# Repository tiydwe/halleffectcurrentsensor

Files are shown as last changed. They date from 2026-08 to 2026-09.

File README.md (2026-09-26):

# Handheld Hall Effect Current Sensor

This is a handheld hall effect current sensor, a device used to measure current without needing to directly touch the circuit being measured.
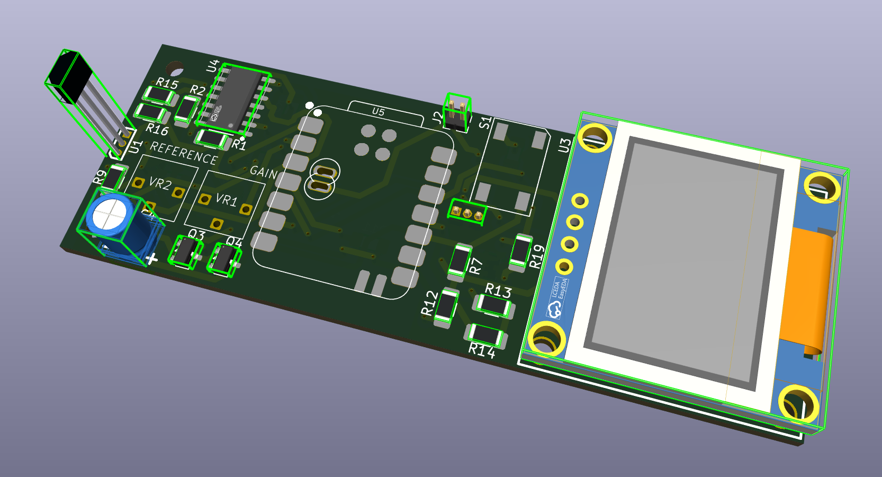
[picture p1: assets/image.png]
screenshot of a pcb

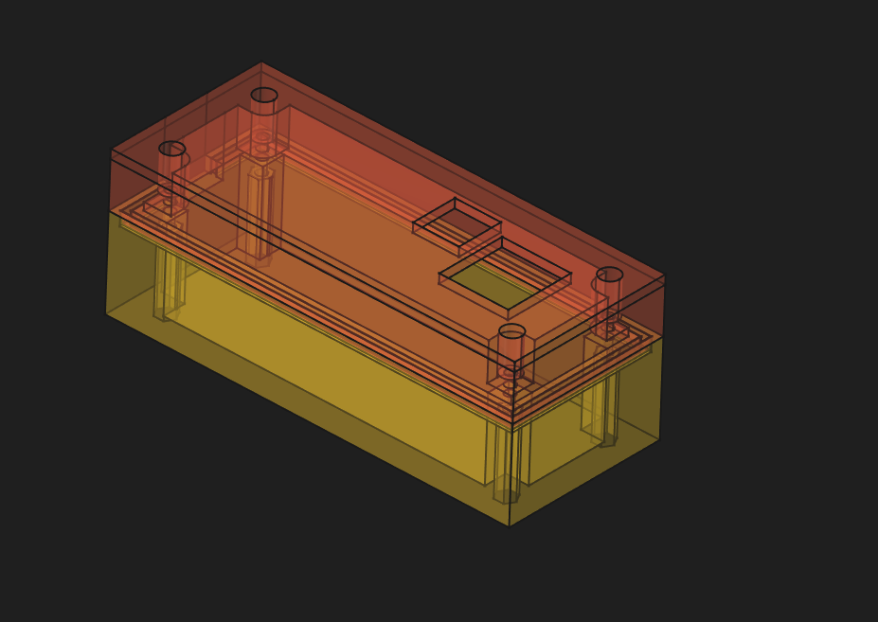
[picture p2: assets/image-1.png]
screenshot of cad model


# Features
* Completely contained on one handheld case, including battery
* Self powered!
* OLED screen for easy measurement
* Two adjustable calibration resistors for easy calibration

# Assembly
The handheld hall effect current sensor is easily assembled with just 4 parts:
* The bottom part of case
* The battery, which sits in the bottom part of case
* The PCB, which goes between the top and bottom part of the case
* The top part of the case

It is held together with 4 M2 screws and 4 M2 nuts.

# Technical stuff

The hall effect voltage output is fed into an insturmentation amplifier to subtract it from the known zero current voltage and amplify the result. Both the gain and the reference voltage can be easily adjusted with two variable resistors on the PCB. The output of the insturmentation amplifier goes into a Seeed Studio nrf52840 microcontroller's ADC where it is processed. The current reading is then written onto the OLED.

The whole system is powered from a lipo battery, which is regulated to 3.3v by the Seeed Studio microcontroller. An additional [3.3v to 5v off-board converter](https://www.amazon.com/Comidox-Module-Voltage-Converter-0-9-5V/dp/B07L76KLRY/) is used to power the op amp and hall effect sensor.

# IMAGES
Full schematic:
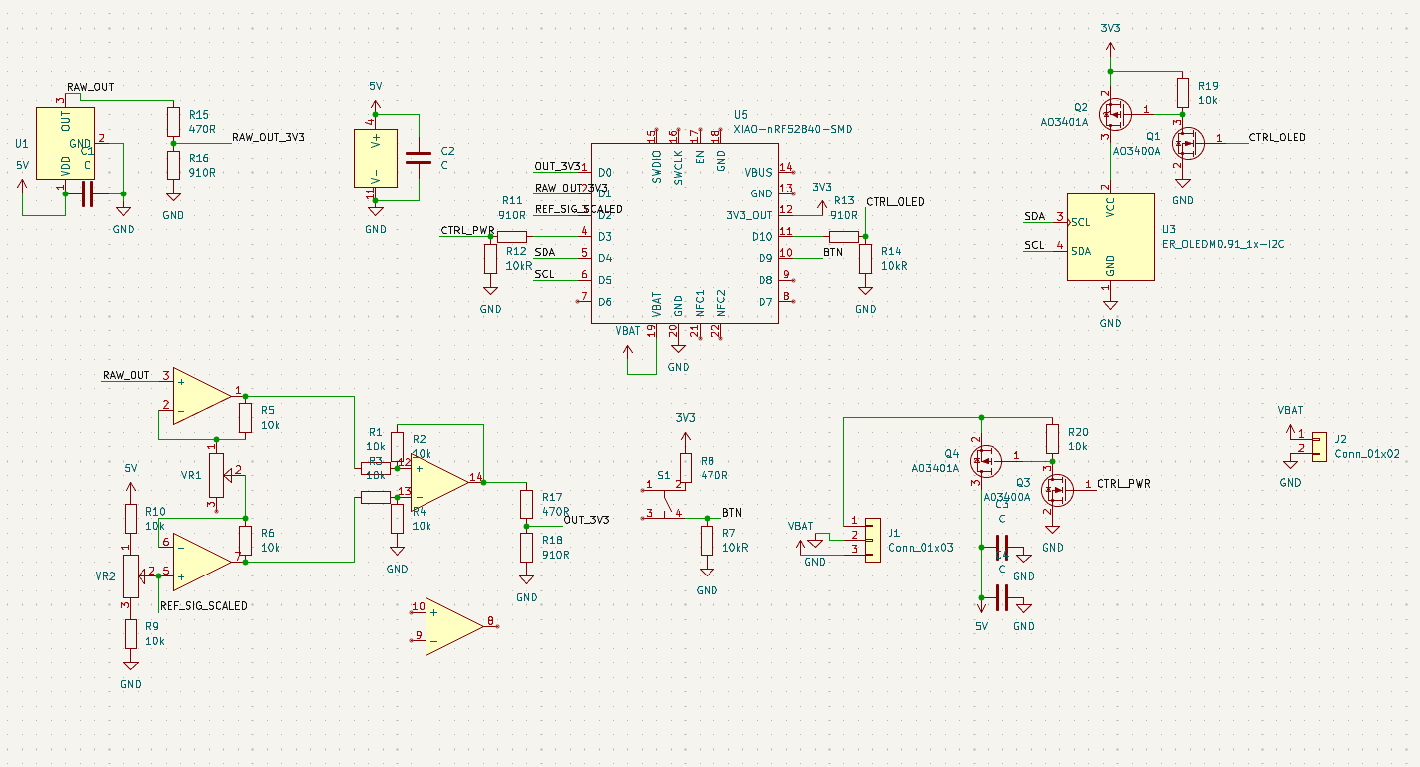
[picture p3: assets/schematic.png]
screenshot of schematic


PCB layout:
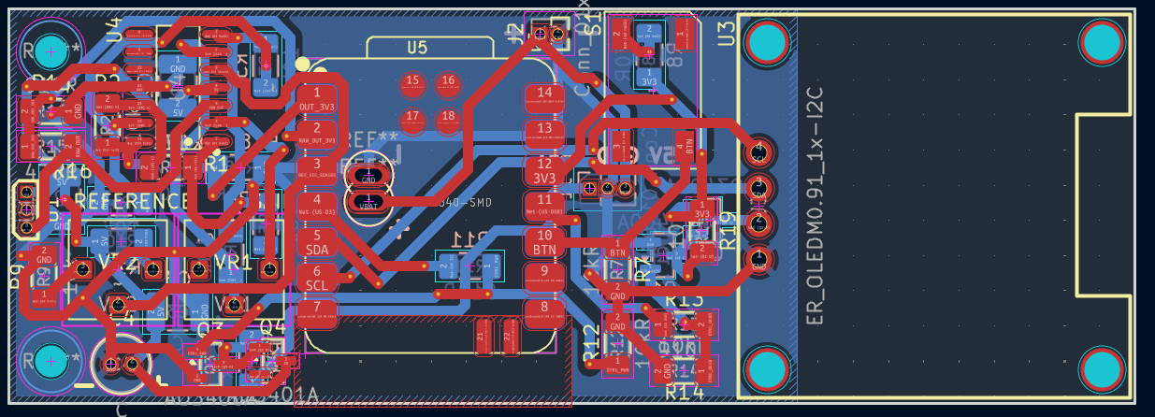
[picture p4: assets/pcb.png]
screenshot of pcb layout


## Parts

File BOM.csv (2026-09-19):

Item Name | Qty | Price (total) (USD) | Item link | Notes
C18189021 | 5 | $0.97 | https://www.lcsc.com/product-detail/C18189021.html | Hall effect sensor
C7463387 | 3 | $1.46 | https://www.lcsc.com/product-detail/C7463387.html | Op amp + 2 extras in case I break one
C5248080 | 1 | 2.3 | https://www.lcsc.com/product-detail/C5248080.html? | OLED
C49451350 | 10 | 0.42 | https://www.lcsc.com/product-detail/C49451350.html | 100nF caps
C53261042 | 20 | 0.45 | https://www.lcsc.com/product-detail/C53261042.html | N-mosfet
C2836398 | 20 | 0.52 | https://www.lcsc.com/product-detail/C2836398.html | P-mosfet
C7528752 | 10 | 0.26 | https://www.lcsc.com/product-detail/C7528752.html | Tactile button
C2933707 | 100 | 0.63 | https://www.lcsc.com/product-detail/C2933707.html | 470 ohm resistor
C2930433 | 100 | 0.59 | https://www.lcsc.com/product-detail/C2930433.html | 910 ohm resistor
LCSC shipping (est) |  | 15 |  | approx
XIAO nRF52840 | 1 | 9.99 | https://www.seeedstudio.com/Seeed-XIAO-BLE-nRF52840-p-5201.html
Seeed studio shipping |  | 7.26
1Ah lipo battery | 1 | 6.49 | https://www.amazon.com/AKZYTUE-1000mAh-Battery-Rechargeable-Protection/dp/B0FRFYJ32K
Ferrite core (pack of 5) | 1 | 8.09 | https://www.amazon.com/gp/product/B07YJXRN6V/ref=ewc_pr_img_2
M2 screw kit | 1 | 8.3 | https://www.amazon.com/Fgruh-1200PCS-Assortment-Washers-Assorted/dp/B0FGV5K8BT?th=1 | Best way I could find to get screws
PCB - OSHPARK | 1 | 17.35 |  | Cheaper than JLCPCB when including shipping
Total Price (USD): |  | $80.08

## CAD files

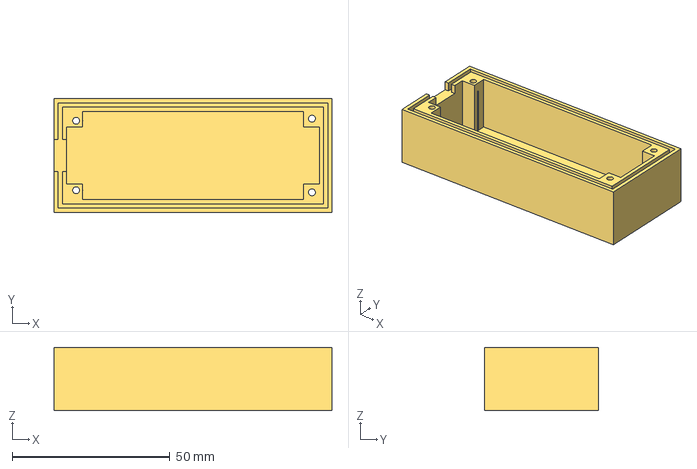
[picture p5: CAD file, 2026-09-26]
cad/case-bottom.step
88.0 x 36.0 x 20.0 mm

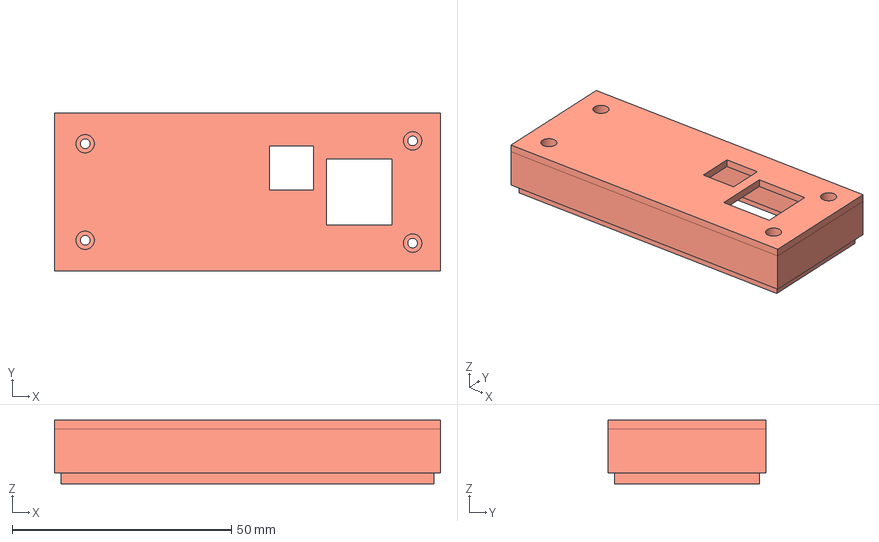
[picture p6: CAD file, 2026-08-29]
production/case-top.step
88.0 x 36.0 x 14.5 mm

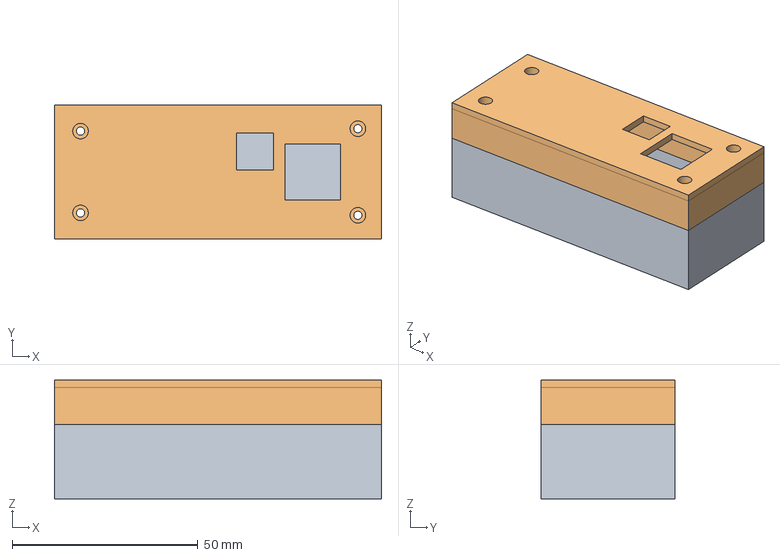
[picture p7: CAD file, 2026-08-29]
cad/case.FCStd
88.0 x 36.0 x 32.0 mm
bottom
top

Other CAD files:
cad/case-top.step
production/case-bottom.step

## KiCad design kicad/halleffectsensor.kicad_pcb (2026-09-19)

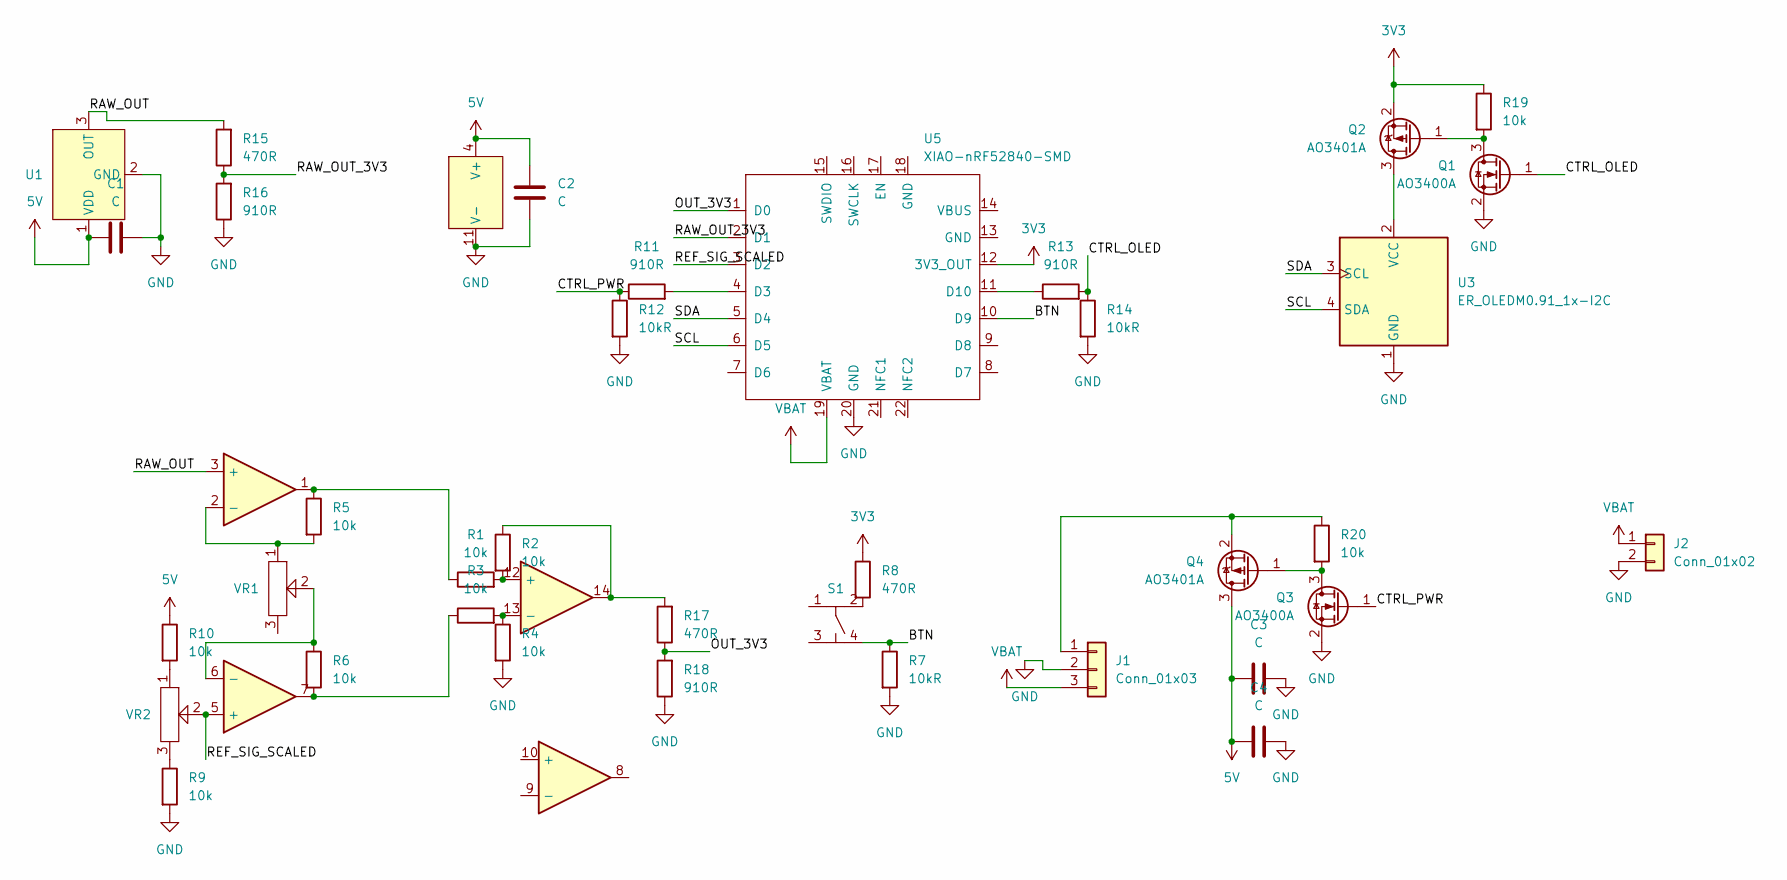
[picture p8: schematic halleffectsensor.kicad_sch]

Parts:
C1, C2, C3: C; C_1210_3225Metric_Pad1.33x2.70mm_HandSolder
C4: C; C_Radial_D4.0mm_H7.0mm_P1.50mm
J1: Conn_01x03; PinHeader_1x03_P1.27mm_Vertical
J2: Conn_01x02; PinHeader_1x02_P1.27mm_Vertical
Q1, Q3: AO3400A; SOT-23
Q2, Q4: AO3401A; SOT-23
R1, R2, R3, R4, R5, R6, R9, R10, R19, R20: 10k; R_1206_3216Metric_Pad1.30x1.75mm_HandSolder
R7, R12, R14: 10kR; R_1206_3216Metric_Pad1.30x1.75mm_HandSolder
R8, R15, R17: 470R; R_1206_3216Metric_Pad1.30x1.75mm_HandSolder
R11, R13, R16, R18: 910R; R_1206_3216Metric_Pad1.30x1.75mm_HandSolder
S1: SOIC-4
U1: TO-92S-3_L4.1-W1.7-P1.27-L
U3: ER_OLEDM0.91_1x-I2C; OLED-TH_L27.8-W27.2-P2.54_C9900033791
U4: SOP-14_L8.6-W3.9-P1.27-LS6.0-BL
U5: XIAO-nRF52840-SMD
VR1, VR2: Potentiometer_3_pi

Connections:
3V3: Q2.2 (S), R8.1, R19.1, U5.12 (3V3_OUT)
5V: C1.1, C2.2, C3.2, C4.2, Q4.3 (D), R10.1, U1.1 (VDD), U4.4 (V+)
/BTN: R7.1, S1.4, U5.10 (D9)
/CTRL_OLED: Q1.1 (G), R13.2, R14.1
/CTRL_PWR: Q3.1 (G), R11.1, R12.1
/OUT_3V3: R17.1, R18.2, U5.1 (D0)
/RAW_OUT: R15.2, U1.3 (OUT), U4.3 (+)
/RAW_OUT_3V3: R15.1, R16.2, U5.2 (D1)
/REF_SIG_SCALED: U4.5 (+), U5.3 (D2), VR2.2
/SCL: U3.4 (SDA), U5.6 (D5)
/SDA: U3.3 (SCL), U5.5 (D4)
GND: C1.2, C2.1, C3.1, C4.1, J1.2, J2.2, Q1.2 (S), Q3.2 (S), R4.2, R7.2, R9.2, R12.2, R14.2, R16.1, R18.1, U1.2 (GND), U3.1 (GND), U4.11 (V-), U5.20 (GND)
unnamed: J1.1, Q4.2 (S), R20.1
unnamed: Q1.3 (D), Q2.1 (G), R19.2
unnamed: Q2.3 (D), U3.2 (VCC)
unnamed: Q3.3 (D), Q4.1 (G), R20.2
unnamed: R1.1, R5.1, U4.1
unnamed: R3.1, R6.2, U4.7
unnamed: R8.2, S1.2
unnamed: R9.1, VR2.3
unnamed: R10.2, VR2.1
unnamed: R2.1, R17.2, U4.14
unnamed: R5.2, U4.2 (-), VR1.1
unnamed: R6.1, U4.6 (-), VR1.2
unnamed: R1.2, R2.2, U4.12 (+)
unnamed: R3.2, R4.1, U4.13 (-)
unnamed: R11.2, U5.4 (D3)
unnamed: R13.1, U5.11 (D10)
VBAT: J1.3, J2.1, U5.19 (VBAT)

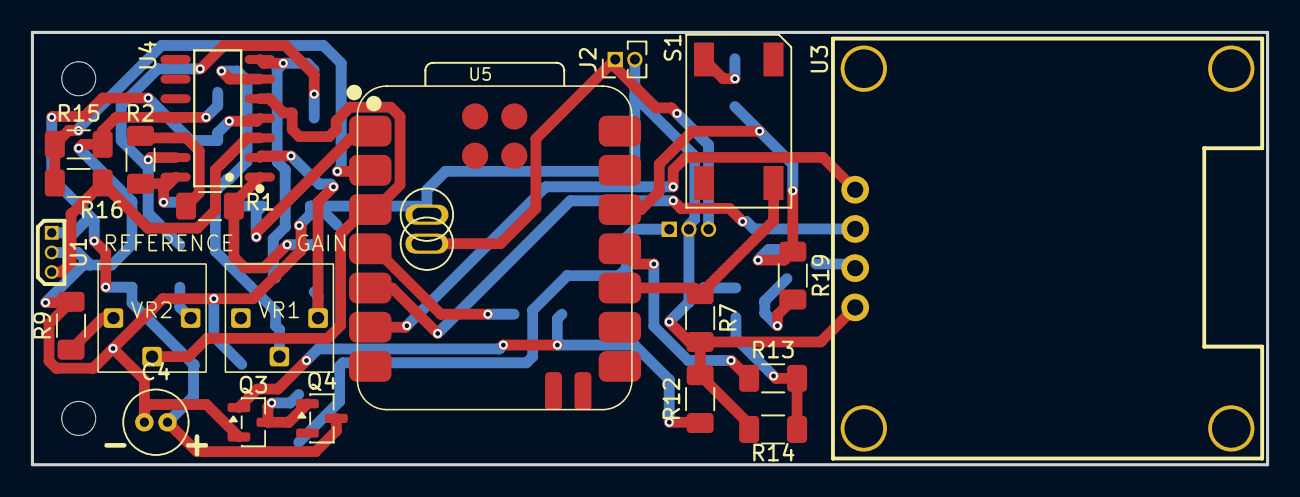
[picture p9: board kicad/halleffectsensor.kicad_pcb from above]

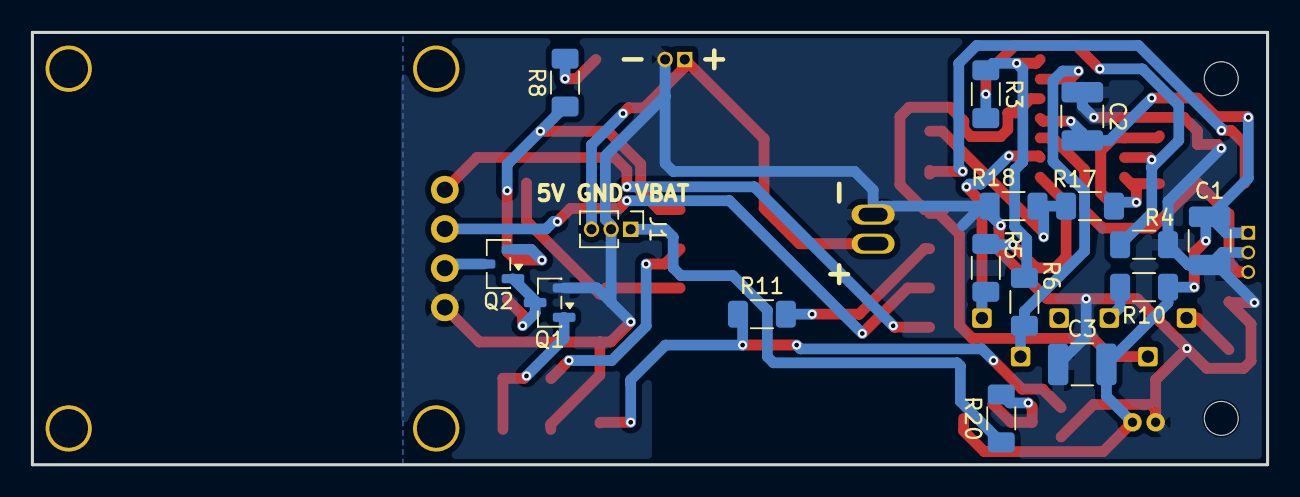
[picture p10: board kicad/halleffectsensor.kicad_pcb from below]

Board: 2 copper layers, 80.0 x 28.0 mm, 37 parts (16 on the bottom side), 29 nets.

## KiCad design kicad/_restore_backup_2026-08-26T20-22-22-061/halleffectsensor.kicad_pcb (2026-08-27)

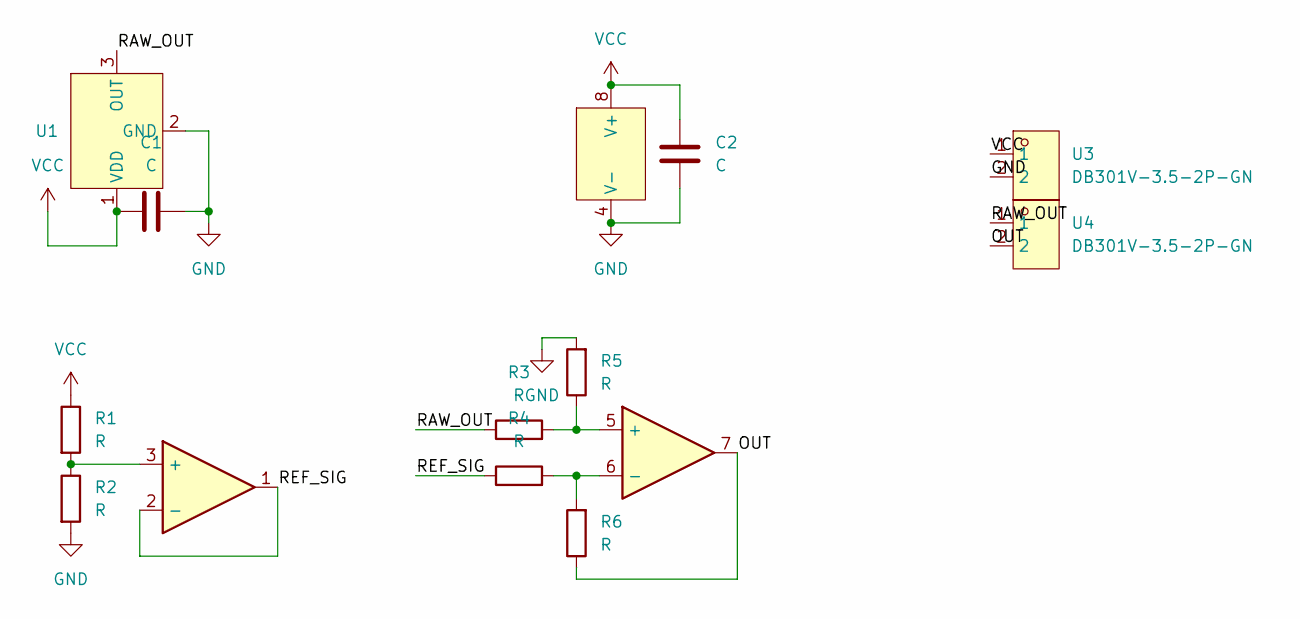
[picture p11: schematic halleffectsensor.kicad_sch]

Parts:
C1, C2: C; C_1210_3225Metric_Pad1.33x2.70mm_HandSolder
R1, R2, R3, R4, R5, R6: R; R_Axial_DIN0204_L3.6mm_D1.6mm_P7.62mm_Horizontal
U1: TO-92S-3_L4.1-W1.7-P1.27-L
U2: COS5532DT; DIP-8_L9.3-W6.4-P2.54-LS7.6-BL; LCSC Part C5155885
U3, U4: DB301V-3.5-2P-GN; CONN-TH_DB301V-3.5-2P-GN; LCSC Part C695629

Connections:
/OUT: R6.1, U2.7, U4.2
/RAW_OUT: R3.1, U1.3 (OUT), U4.1
/REF_SIG: R4.1, U2.1, U2.2 (-)
GND: C1.2, C2.1, R2.2, R5.2, U1.2 (GND), U2.4 (V-), U3.2
unnamed: R1.2, R2.1, U2.3 (+)
unnamed: R3.2, R5.1, U2.5 (+)
unnamed: R4.2, R6.2, U2.6 (-)
VCC: C1.1, C2.2, R1.1, U1.1 (VDD), U2.8 (V+), U3.1

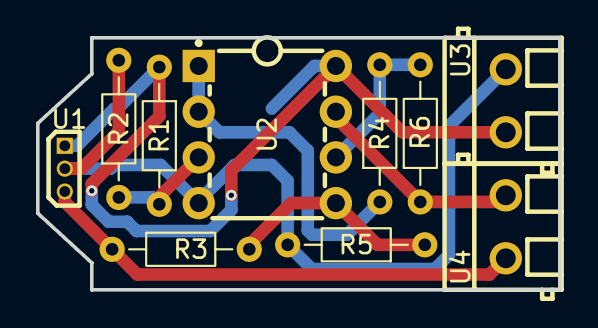
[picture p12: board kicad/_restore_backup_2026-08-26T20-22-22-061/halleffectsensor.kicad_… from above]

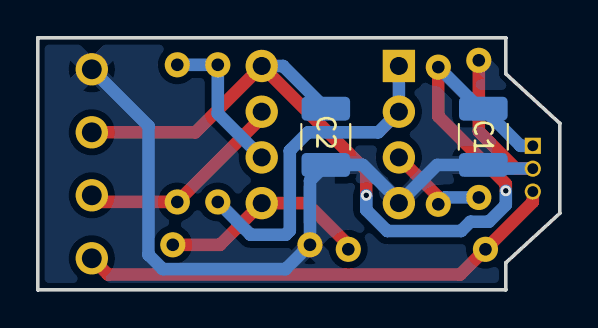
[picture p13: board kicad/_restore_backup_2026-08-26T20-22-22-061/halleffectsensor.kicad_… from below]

Board: 2 copper layers, 29.0 x 14.0 mm, 12 parts (2 on the bottom side), 8 nets.

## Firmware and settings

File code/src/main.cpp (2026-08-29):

#include <Arduino.h>
#include <bluefruit.h>
#include <Adafruit_SPIFlash.h>

#include "config.h"
#include "OLED.h"
#include "sense.h"
#include "utility.h"

#if defined(CUSTOM_CS) && defined(CUSTOM_SPI)
  Adafruit_FlashTransport_SPI flashTransport(CUSTOM_CS, CUSTOM_SPI);

#elif defined(ARDUINO_ARCH_ESP32)
  Adafruit_FlashTransport_ESP32 flashTransport;

#else
  #if defined(EXTERNAL_FLASH_USE_QSPI)
    Adafruit_FlashTransport_QSPI flashTransport;

  #elif defined(EXTERNAL_FLASH_USE_SPI)
    Adafruit_FlashTransport_SPI flashTransport(EXTERNAL_FLASH_USE_CS, EXTERNAL_FLASH_USE_SPI);

  #else
    #error No QSPI/SPI flash are defined on your board variant.h !
  #endif
#endif

Adafruit_SPIFlash flash(&flashTransport);

long pushStart = 0;
bool wasPushed = false;

void go_to_sleep();

void setup() {
 init_sensors();
 init_OLED();
 pinMode(BTN, INPUT);
 nrf_gpio_cfg_sense_input(
    g_ADigitalPinMap[BTN],
    NRF_GPIO_PIN_NOPULL,
    NRF_GPIO_PIN_SENSE_HIGH
  );
}

void loop() {
  auto out = read_OUT();
  auto raw_out = read_RAW_OUT();
  auto ref_sig = read_REF_SIG();
  OLED_display.clearDisplay();
  OLED_display.setCursor(0, 0);
  OLED_display.printf("Current: %.2fA*factor\n", out);
  OLED_display.printf("Reference V: %.2f A\n", ref_sig);
  OLED_display.printf("Raw voltage: %.2f V\n", raw_out);
  if(out > 4.5){
    OLED_display.println("WARNING! Current may be");
    OLED_display.println("wrong! High current!");
  }
  else{
    OLED_display.println("");
    OLED_display.println("");
  }
  OLED_display.println("To power off, hold the");
  OLED_display.println("power button for 5 s");
  
  if(digitalRead(INPUT) == HIGH){
    if(wasPushed){
      if(millis() - pushStart > 5000){
        go_to_sleep();
      }
    }
    else{ 
      wasPushed = true;
      pushStart = millis();
    }
  }
  else{
    wasPushed = false;
  }
  delay(50);
}

// HOW TO WAKE UP FROM SLEEP FROM GPIO PIN???
// ANYONE?
void go_to_sleep(){
  sensors_off();
  OLED_off();
  flash.begin();
  flashTransport.begin();
  if(flashTransport.runCommand(0xB9) == false){
    pinMode(LED_BUILTIN, OUTPUT);
    digitalWrite(LED_BUILTIN, LOW);
    while(true){
      yield();
    }
  }
  flashTransport.end();
  flash.end();
}

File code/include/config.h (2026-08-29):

#ifndef CONFIG_H
#define CONFIG_H

#include <Arduino.h>

// PINS
#define OUT_3V3 A0
#define RAW_OUT_3V3 A1
#define REF_SIG_SCALED A2
#define CTRL_PWR D3
#define CTRL_OLED D10
//#define SDA 5
//#define SCL 6
#define BTN D9

// OLED
#define OLED_SCREEN_WIDTH 128
#define OLED_SCREEN_HEIGHT 64
#define OLED_ADDRESS 0x3C
#define OLED_RESET_PIN -1

// SENSOR
#define CONVERT_3V3_5V (((long double)5.0) / 3.3)
#define READ_CNT 10

#endif

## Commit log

2026-08-27 Did more pcb design
    [BOM.csv, halleffectsensor.kicad_pcb, halleffectsensor.kicad_sch]
2026-08-27 Finished PCB and BOM
    [BOM.csv, case-bottom.step, case.FCStd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]
2026-08-28 Fix BOM link for pcb
    [BOM.csv]
2026-08-28 Revise README for handheld Hall Effect sensor project
2026-08-29 Continued CAD work
    [case-bottom.step, case-top.step, case.FCStd]
2026-08-29 Update pcb because github didn't work for some reason
    [halleffectsensor-B_Cu.gbr, halleffectsensor-B_Mask.gbr, halleffectsensor-B_Paste.gbr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]
2026-08-29 Worked on the code and fixed an issue with pcb
    [halleffectsensor.kicad_pcb, halleffectsensor.kicad_sch]
2026-08-29 Fix BOM and update pcb
    [BOM.csv, halleffectsensor.kicad_pcb]
2026-08-29 remove oshpark link from BOM
    [BOM.csv]
2026-08-29 Remove plated through holes and remove item from BOM no longer needed
    [BOM.csv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]
2026-09-04 Add production folder and make BOM more accurate for LCSC shipping
    [BOM.csv, case-bottom.step, case-top.step]
2026-09-19 Fixed the high side mosfets
    [BOM.csv, case-bottom.step, case-top.step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]
2026-09-19 update gerbers
    [halleffectsensor-B_Cu.gbl, halleffectsensor-B_Mask.gbs, halleffectsensor-B_Paste.gbp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]
2026-09-26 Update to comply with most recent review
    [case-bottom.step, case-top.step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]
